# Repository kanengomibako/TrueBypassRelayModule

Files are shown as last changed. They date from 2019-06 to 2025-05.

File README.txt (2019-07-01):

True Bypass Relay Module

ブログ記事→https://drugscore.blog.fc2.com/blog-entry-244.html

秋月電子にある特価ラッチリレーEA2-5TNAGを利用したトゥルーバイパスモジュールです。ロジックICを利用しているのでプログラミングが不要です。TC4069UBP、TC74HCU04APで動作確認しています。在庫限りの部品が多いのでご注意ください。

参考サイト→Using a latching relay driver for true bypass(http://www.fredric.co.uk/blog/134-Using-a-latching-relay-driver-for-true-bypass)

当初ラッチリレーのピン配置の表裏が逆というミスがあったので、公開しているデータはエラー修正済のRev.B基板です。エラー修正前のRev.A基板をお持ちの方は必ず修正方法をご確認下さい。

＜接続方法＞
SW1→モーメンタリスイッチをつなぎます。接続は左右入れ替わってもOKです。
LED→エフェクトオン時に点灯するLEDをつなぎます。四角いパッドになっている方がカソード側です。
GND→GNDをつなぎます。
IN→入力ジャックをつなぎます。
OUT→出力ジャックをつなぎます。
SND→エフェクター基板の入力へつなぎます。
RTN→エフェクター基板からの出力をつなぎます。
VCC→+9V電源をつなぎます。

＜エラーありRev.A基板の修正方法＞
ラッチリレーをそのままの向き（棒状の印が付いている方が下側）で裏側に取り付けます。スペースの都合で裏側に取り付けられない場合は、LEDの配線を変えます。+5VがきているところにLEDのアノードをつなぎ、LEDのアノードを接続するはずだったところにLEDのカソードをつなぎます。

＜パーツリスト＞
7	100n	C1, C2, C3, C4, C5, C6, C7 ※積層セラミックコンデンサ
1	10u	C8　※電解コンデンサ

1	1k	R3
2	10k	R6, R7
3	100k	R1, R4, R5
1	1M	R2

3	1N4148	D1, D2, D3
1	LED	D4

2	2SC1815-GR	Q1, Q2
1	EA2-5TNAG	U1
1	TC4069UBP	U2
1	78L05	U3

1	FS	SW1　※SPSTモーメンタリスイッチ

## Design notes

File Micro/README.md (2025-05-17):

# True Bypass Relay Module Micro

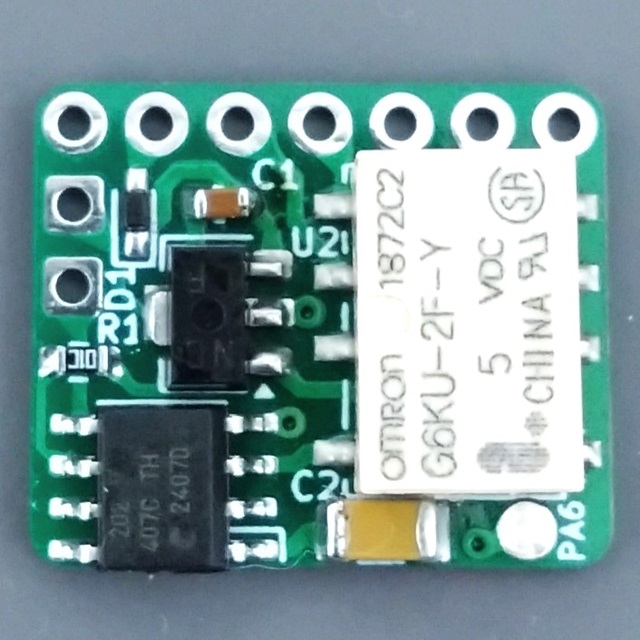
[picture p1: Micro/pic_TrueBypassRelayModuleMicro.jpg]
<br>

モーメンタリースイッチを接続して、エフェクターのトゥルーバイパスとインジケーターLED切替を行うことができるモジュールです。

### 配線方法

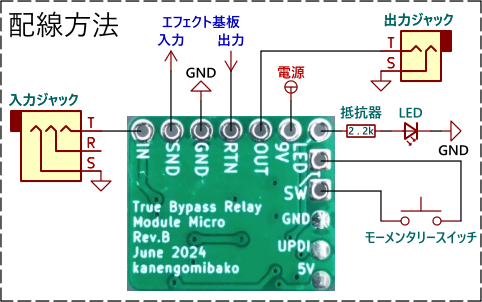
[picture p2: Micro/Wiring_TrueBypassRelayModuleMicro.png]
<br>

- IN → 入力ジャック
- SND → エフェクト基板の入力
- GND → グラウンド（アース）
- RTN → エフェクト基板の出力
- OUT → 出力ジャック
- 9V → 電源
- LED → LEDの電流制限抵抗とLED<br>※ エフェクトオン時に5Vが出力されます。電流制限抵抗の抵抗値は470Ω以上を推奨します。
- SW → スイッチ（接続は上下入れ替わってもOK）<br>※ モーメンタリー（モメンタリ）のスイッチを使用します。SPST（単極単投、1回路1接点）のものが入手しやすいです。

### 機能設定
スイッチを押す度にエフェクトオンとバイパスが切り替わる通常モードと、スイッチを押している間のみエフェクトオンになるモーメンタリーモードがあります。また、電源を入れたときに自動でエフェクトオンにするかどうかを設定できます。設定は自動保存され、電源を切っても記憶されています。

- 起動時エフェクトオン機能切替<br>スイッチを押しながら電源を入れます。設定完了時にLEDが2回点滅します。
- モーメンタリーモード・通常モード切替<br> スイッチを押しながら電源を入れ、そのまま約3秒間スイッチを押し続けます。設定完了時にLEDが3回点滅します。<br>※ モーメンタリーモードの状態で起動時エフェクトオンに設定にすると、スイッチを押している間のみバイパス状態となるモードになります。

### 資料
- [True Bypass Relay Module Micro 製作に関する記事](https://kanengomibako.github.io/pages/00349.html)

| 主な仕様 |  |
| - | - |
| 出荷時設定 | 通常モード　起動時エフェクトバイパス |
| 使用可能電源電圧範囲 | 7V ～ 20V |
| 消費電流 | 3mA（オン・オフ切替の一瞬のみ21mA消費電流増加） |
| 外形寸法 | 幅 18 mm × 奥行 15 mm × 高さ 7 mm |
| 質量 | 約 1.5 g |

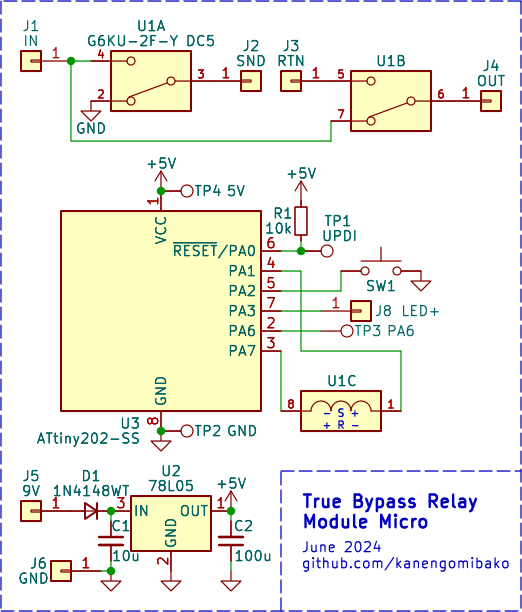
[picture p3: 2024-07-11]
Micro/TrueBypassRelayModuleMicro_Schematic.png

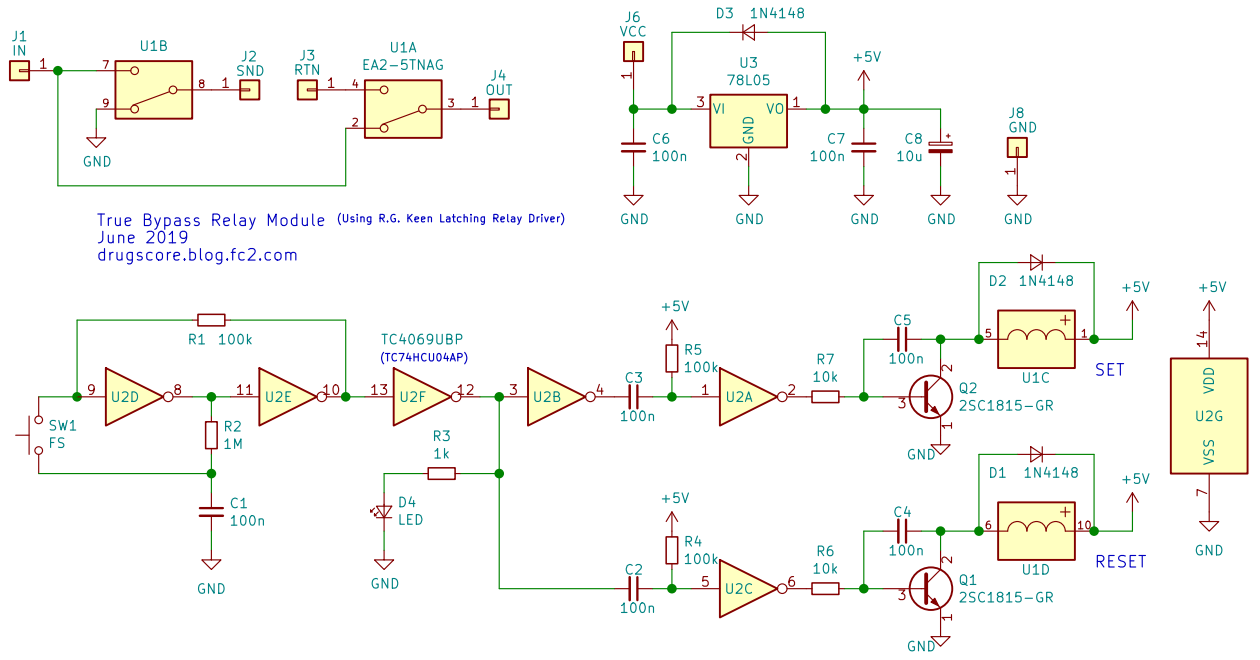
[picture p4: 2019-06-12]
Normal/TrueBypassRelayModule_sch.png

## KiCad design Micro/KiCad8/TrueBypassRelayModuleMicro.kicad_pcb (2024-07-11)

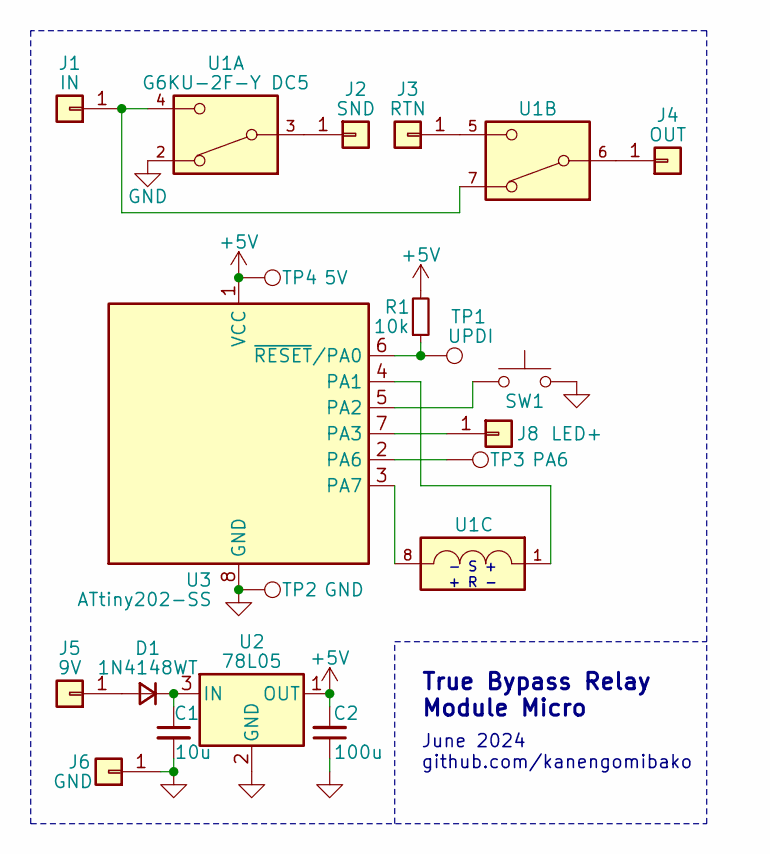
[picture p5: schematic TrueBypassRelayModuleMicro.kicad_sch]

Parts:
C1: 10u; C_0603_1608Metric
C2: 100u; C_1206_3216Metric
D1: 1N4148WT; D_SOD-523_HandSoldering
J1: IN; my_WirePad_1mmDrill
J2: SND; my_WirePad_1mmDrill
J3: RTN; my_WirePad_1mmDrill
J4: OUT; my_WirePad_1mmDrill
J5: 9V; my_WirePad_1mmDrill
J6: GND; my_WirePad_1mmDrill
J8: LED+; my_WirePad_1mmDrill
R1: 10k; R_0603_1608Metric
SW1: SW1; PinHeader_1x02_P2.54mm_Vertical
TP1: UPDI; my_TestPoint_2mm
TP2: GND; my_TestPoint_2mm
TP3: PA6; my_TestPoint_2mm
TP4: 5V; my_TestPoint_2mm
U1: G6KU-2F-Y DC5; Relay_DPDT_Omron_G6K-2F-Y
U2: 78L05; SOT-89-3
U3: ATtiny202-SS; SOIC-8_3.9x4.9mm_P1.27mm

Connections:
+5V: C2.2, R1.2, TP4.1, U2.1 (OUT), U3.1 (VCC)
GND: C1.2, C2.1, J6.1, SW1.2, TP2.1, U1.2, U2.2 (GND), U3.8 (GND)
unnamed: D1.2 (A), J5.1
unnamed: C1.1, D1.1 (K), U2.3 (IN)
unnamed: J1.1, U1.4, U1.7
unnamed: J2.1, U1.3
unnamed: J3.1, U1.5
unnamed: J4.1, U1.6
unnamed: J8.1, U3.7 (PA3)
unnamed: U1.1, U3.4 (PA1)
unnamed: SW1.1, U3.5 (PA2)
unnamed: TP3.1, U3.2 (PA6)
unnamed: U1.8, U3.3 (PA7)
unnamed: R1.1, TP1.1, U3.6 (~RESET/PA0)

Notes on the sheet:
True Bypass Relay Module Micro
June 2024 github.com/kanengomibako
- S + + R -

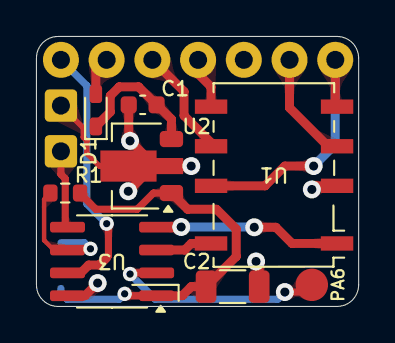
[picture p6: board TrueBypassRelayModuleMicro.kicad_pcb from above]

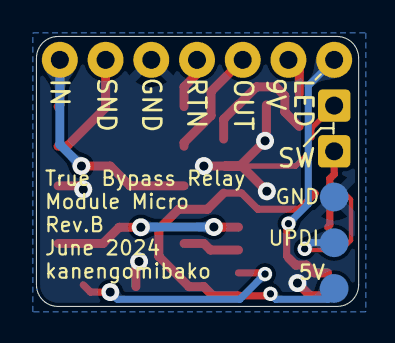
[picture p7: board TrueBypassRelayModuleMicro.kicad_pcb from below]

Board: 2 copper layers, 17.9 x 15.0 mm, 19 parts (11 on the bottom side), 14 nets.

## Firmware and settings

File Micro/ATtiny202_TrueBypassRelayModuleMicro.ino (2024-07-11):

/*
True Bypass Relay Module Micro
v1.0 20240709
https://github.com/kanengomibako

ヒューズビット設定
BOD Mode when Active/Sleeping: Enabled/Enabled
BOD Voltage Level: 3.7V (Unofficial)
Chip: ATtiny202
Clock: 1 MHz internal
Save EEPROM: EEPROM retained
*/

#include <EEPROM.h>

#define SHORT_PUSH_MSEC 10                         // スイッチ短押し時間 ミリ秒
#define RELAY_DRIVE_MSEC 11                        // リレーコイル駆動時間 ミリ秒 16まで
const long shortPushCount = 10 * SHORT_PUSH_MSEC;  // 10カウントで1ms

bool fxState = true;    // エフェクトオンオフ状態 true: オン
long swOnCnt = 0;       // スイッチを押している間カウントアップ
long swOffCnt = 0;      // スイッチを押していない間カウントアップ
int onStart = 1;        // 起動時エフェクトオン設定
int momentaryMode = 0;  // モーメンタリモード設定
const int addr0 = 0;    // EEPROM 起動時オンオフ設定書き込み先アドレス
const int addr1 = 1;    // EEPROM モーメンタリモード設定書き込み先アドレス

// エフェクトオン動作
void fxOn() {
  digitalWrite(PIN_PA7, LOW);
  digitalWrite(PIN_PA1, HIGH);
  delayMicroseconds(1000 * RELAY_DRIVE_MSEC);
  digitalWrite(PIN_PA1, LOW);
  digitalWrite(PIN_PA3, HIGH);  // LED
  fxState = true;
}

// エフェクトオフ動作
void fxOff() {
  digitalWrite(PIN_PA1, LOW);
  digitalWrite(PIN_PA7, HIGH);
  delayMicroseconds(1000 * RELAY_DRIVE_MSEC);
  digitalWrite(PIN_PA7, LOW);
  digitalWrite(PIN_PA3, LOW);  // LED
  fxState = false;
}

// LED点滅
void blink(int n) {
  for (int i = 0; i < n; i++) {
    digitalWrite(PIN_PA3, HIGH);
    delay(50);
    digitalWrite(PIN_PA3, LOW);
    delay(150);
  }
}

// 電源電圧低下時割り込み
ISR(BOD_VLM_vect) {
  PORTA.OUTCLR = PIN3_bm;       // 高速 PA3 LOW (LED)
  PORTA.OUTSET = PIN7_bm;       // 高速 PA7 HIGH
  fxOff();                      // エフェクトオフ発動
  BOD.INTFLAGS = BOD_VLMIF_bm;  // 割り込みフラグクリア
}

void setup() {
  delay(100);  // 電源立ち上がり待機

  // ピン設定
  pinMode(PIN_PA1, OUTPUT);        // PA1: リレーセット エフェクトオン
  pinMode(PIN_PA2, INPUT_PULLUP);  // PA2: スイッチ読み取り 内部プルアップ
  pinMode(PIN_PA3, OUTPUT);        // PA3: LED出力
  pinMode(PIN_PA6, OUTPUT);        // PA6: 不使用
  pinMode(PIN_PA7, OUTPUT);        // PA7: リレーリセット エフェクトバイパス
  digitalWrite(PIN_PA1, LOW);
  digitalWrite(PIN_PA3, LOW);
  digitalWrite(PIN_PA6, LOW);
  digitalWrite(PIN_PA7, LOW);

  // 設定読み込み
  onStart = EEPROM.read(addr0);
  momentaryMode = EEPROM.read(addr1);

  // スイッチを押しながら起動
  while (digitalRead(PIN_PA2) == LOW) {
    swOnCnt++;
    delay(1);
    if (swOnCnt == 20) {  // 短押し時 起動時オンオフ設定変更
      onStart = !onStart;
      EEPROM.write(addr0, onStart);
      blink(2);
    }
    if (swOnCnt == 3000) {  // 長押し時 モーメンタリモード設定変更
      momentaryMode = !momentaryMode;
      onStart = 0;  // 起動時オフ設定にする（スイッチを押している間だけエフェクトオン）
      EEPROM.write(addr0, onStart);
      EEPROM.write(addr1, momentaryMode);
      blink(3);
    }
  }
  swOnCnt = 0;

  // 起動時オンオフ実行
  if (onStart) fxOn();
  else fxOff();

  // 電源電圧低下時割り込み設定
  BOD.VLMCTRLA = BOD_VLMLVL_25ABOVE_gc;              // VLM閾値 3.7V * 1.25 = 4.6V
  BOD.INTCTRL = BOD_VLMIE_bm | BOD_VLMCFG_BELOW_gc;  // VLM割り込み有効 閾値を下回った時発動
}

void loop() {
  if (digitalRead(PIN_PA2) == LOW) {
    swOnCnt++;  // スイッチを押した時カウントアップ
    swOffCnt = 0;
  } else {
    swOffCnt++;  // スイッチを離した時カウントアップ
    swOnCnt = 0;
  }

  if (momentaryMode) {  // モーメンタリーモード
    if (onStart) {      // 起動時エフェクトオン → フットスイッチ押下時にエフェクトオフ
      if (swOnCnt == shortPushCount) fxOff();
      if (swOffCnt == shortPushCount) fxOn();
    } else {  // 起動時エフェクトオフ → フットスイッチ押下時にエフェクトオン
      if (swOnCnt == shortPushCount) fxOn();
      if (swOffCnt == shortPushCount) fxOff();
    }
  } else {  // オルタネートモード
    if (swOnCnt == shortPushCount) {
      fxState = !fxState;
      if (fxState) fxOn();
      else fxOff();
    }
  }

  delayMicroseconds(20);  // ループ一回が0.1msになるよう調整
  //PORTA.OUTTGL = PIN3_bm;  // 高速LEDトグル ループ時間確認用
}

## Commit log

2019-06-12 Create KiCad data
    [TBRM.kicad_pcb, TBRM.sch]
2024-07-08 Reorganized folders
    [TrueBypassRelayModule.kicad_pcb, TrueBypassRelayModule.sch]
2024-07-11 Add True Bypass Relay Module Micro
    [TrueBypassRelayModuleMicro.kicad_pcb, TrueBypassRelayModuleMicro.kicad_sch]
